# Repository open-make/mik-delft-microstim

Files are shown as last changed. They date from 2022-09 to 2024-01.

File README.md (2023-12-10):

# Hardware setup for the "Microstimulation" experiment 
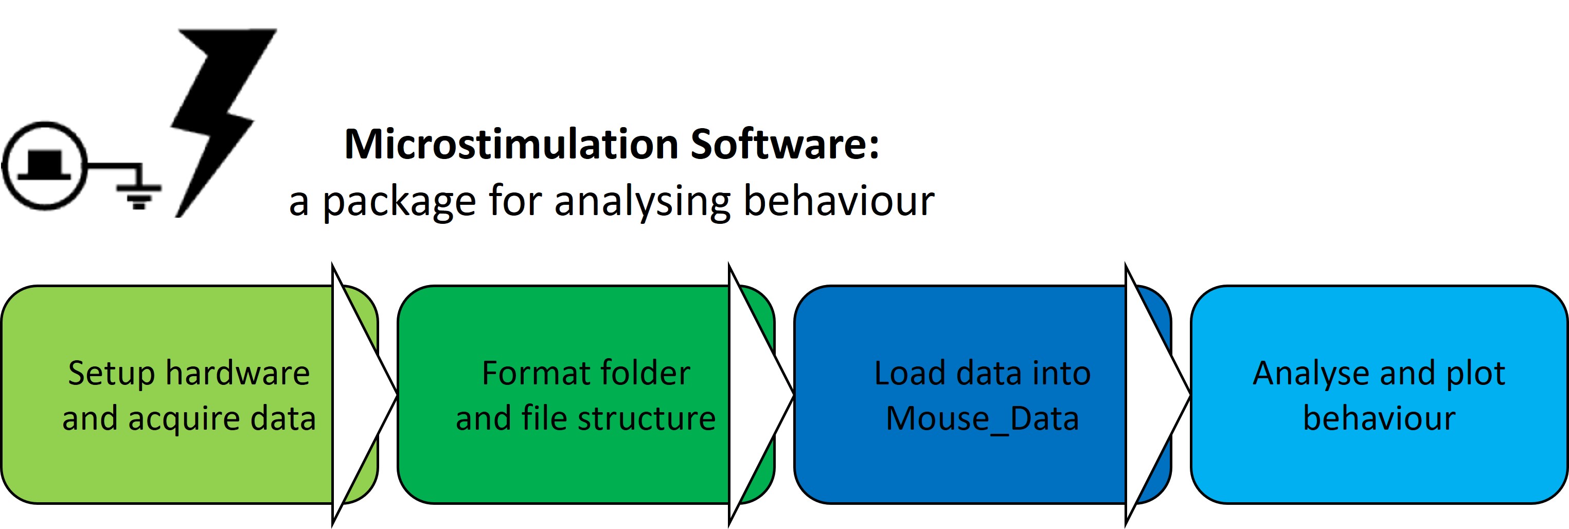
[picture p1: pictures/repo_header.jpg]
header


This repository provides information to set up the "Microstimulation" experiment used in Matthew Larkum's lab, including both *a documentation package of the hardware, the experimental protocol, and the software used for data acquisition* 
We will present here the most recent version which was reworked to use BPOD (Schutte et al. in preparation), we will also refer to the original setup described in (Doron et al., 2020).

In the microstimulation experiment, a *rodent* (usually a mouse) is head fixed. It receives *Intracranial Direct Current stimulation (IDCS)* or  *microstimulation* in the primary somatosensory barrel cortex (S1-BF). The goal of the task is to teach the animal to report the stimulus by licking a water spout during the response window. The animal usually learns to associate a 40 $\mu A$  stimulation with a sugar water (4% sucrose) reward and will lick the water tube upon stimulation. Both a BPOD and a SPIKE2 version of the setup and the protocol exist. 

## Current state of the project

The hardware can be defined as a prototype, as most self-assembled setups in neurobiology labs. Most components are not open source, and expensive. Note that things like the camera holder, rod-connector or head-bar holder can be found as 3D printable files from the [SimpleScienceSetup](https://github.com/mik-schutte/SimpleScienceSetup) project.

The current version uses [BPOD](https://sanworks.io/shop/products.php?productFamily=bpod) technology and [MATLAB](mathworks.com/campaigns/products/trials.html?gclid=CjwKCAiAmsurBhBvEiwA6e-WPC8ymdKjoKsw-h0QvnPUYUxUiHMEaFBh7Eg0xaEl5rYMuemgdsWKdBoC2_kQAvD_BwE&ef_id=CjwKCAiAmsurBhBvEiwA6e-WPC8ymdKjoKsw-h0QvnPUYUxUiHMEaFBh7Eg0xaEl5rYMuemgdsWKdBoC2_kQAvD_BwE:G:s&s_kwcid=AL!8664!3!462958882966!e!!g!!matlab%20download&s_eid=ppc_10961695282&q=matlab+download&gad_source=1) scripts, while the original setup used [CED 1401 and SPIKE2](https://ced.co.uk/products/spkovin). 

The goal of this repository is to provide a step-by-step guide for a non-engineer (neuroscientist) to create, build, implement and do experiments on the setup. The **future** of the project holds implementations for probe recordings, 2P-imaging and widefield imaging.

## Overview of the microstimulation setup

The microstimulation setup can be subdivided into several compartments:

* The [base setup](10_basesetup/base_readme.md): Components need to be brought together, everything needs to be grounded and vibration resistant. The elements should be hooked to the computer with possibly a good time synchronisation and cable management. Finally, micromanipulators should be positioned to maximize safe movement in the setup.

* The [animal restrains](11_animalrestrains/AR_readme.md): Headfixation and animal restrainment to allow for electrode insertion with limited discomfort. Positioning of the mouse holder should allow for flexibility for between-animal differences.

* The [water reward system](12_water-reward/WR_readme.md): The lick detector, the multitool, the solenoid, the tubing and the water container. Allowing for a quantified, timed and reliable distribution of the water reward.

* The [electrical compartment for stimulation and eventually recording](13_stimulation-recoding/stim_rec_readme.md): Comprised of the arduino pulse configurator, the stimulus isolator, the electrode, and the electrode holder. Together, they are used to generate an electrical stimulation that's emitted through the electrode.

* The [camera compartment](14_videorecording/vid_r_readme.md): Contains the cameras, the camera holders, the lenses, the infra-red and the UV-light. Collectively they allow for the recording of animal behaviour such as pupil dilation and whisker movement.

All compartments put together create a setup that should roughly look like this. 

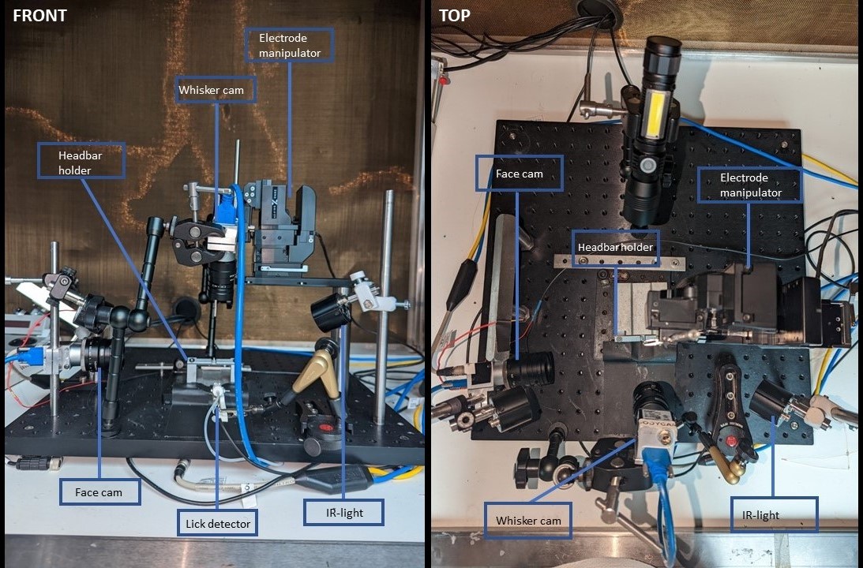
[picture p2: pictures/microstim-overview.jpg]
Overview of the setup from the side and from above


## Description of repository content

This repository largely follows a similar structure as the setup. Each hardware compartment (see above) has their own folder with a README, a bill of materials, build instructions and a wiring diagram. This allows for a modular and more flexible setup that is necessary for easy adoption. 

You'll notice that sometimes a difference is made between version 0 and version 1. This means that there is a difference in this compartments laboratory interface. The laboratory interface is used to coordinate the experiments here it determines what to do with licking input, when to give a microstimulation and when to start saving frames. Version 0 corresponds to the SPIKE2 implementation and version 1 to the BPOD implementation.

## The Software

On top of the hardware documentation we also provide a software package for analysing behavioural and video data. All can be found on the GitHub page for [Microstimulation analysis](https://github.com/mik-schutte/Microstimulation). We have already created a notebook on how to perform analysis. We highly-reccomend checking it out for those with similar data.

## How to contribute 

If you have been reading until here, you can probably help us make this documentation better. Please contact us per email or via an issue in this repository, especially if you are using this documentation, if you have some comments or ideas for improvement, if you want to reuse this hardware for similar or dissimilar experiments or if you just want to say hello. 

## Acknowledgements

The core team members are Mik Schutte and Jelte de Vries. Both of us are employed by the Humboldt University and PhD-students in the Larkum lab and are being supervised by Dr. Robert Sachdev. Primary development was performed by Dr. Guy Doron and transferred by Moritz Druke. Data-management and the supervision concerning open source is done by Dr. Julien Colomb. Lastly, we thank the Delft Open Hardware Academy for its many valuable lessons in designing, project management and hardware documentation.

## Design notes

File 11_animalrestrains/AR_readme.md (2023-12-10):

# Animal Restraint Compartment

The animal restraints section focuses on head fixation and animal restraint to facilitate electrode insertion while ensuring minimal discomfort for the subject. Considerations are made to provide a comfortable experience during experiments.

## Purpose
Prioritizing minimal discomfort and adapting to biological and surgical deviations is pivotal. This approach ensures the animal's comfort throughout the experiments, contributing to standardized and reliable video data acquisition. By minimizing stress or discomfort, the animal is better poised to participate comfortably in experimental tasks while supporting consistent data collection.

The design and setup of the animal restraint compartment considers the well-being of the subject, aligning with ethical considerations and the need for standardized data acquisition protocols. Two main points are to be optimized:

1. **Headfixation:** Enabling stable head positioning for precise electrode insertion and minimizing movement during experiments.
   
2. **Comfort and Flexibility:** Positioning of the mouse holder is designed to accommodate variations between animals, ensuring adaptability for different biological and surgical conditions. This flexibility is crucial for maintaining the animal's comfort and enabling consistent experimental procedures.

### Testing 
Anna Nasr, is working on a deep-learning based system for analyzind animal discomfort using the grimace scale (to be published).

## Necessary Tools

To build the animal restraint, You will need to have build the [base setup](10_basesetup\base_readme.md). Other than that, you will need the following tools:

- Plastic tube
- Headbar holder
- Rod connector
- 5cm rod
- 6mm hex screw (x4)
- 3mm nut

Some components such as the rod connector and a headbar holder are available as 3D printable files in the [SimpleScienceSetup]((https://github.com/mik-schutte/SimpleScienceSetup). Additionally, the exact tools used here, as well as, alternatives can be found in this folder's [bill of materials]().

## Build instructions

Animal Restraint Build

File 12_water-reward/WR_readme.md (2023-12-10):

# Water Reward Compartment

The water reward compartment within the microstimulation setup comprises distinct components crucial for precise and controlled delivery of rewards to the subject, usually a rodent, during experimental tasks. Each component serves a specific function in managing and administering the water reward.

## Components and Functionality

1. **Piezo Sensor Lick Detector:** This sensor is utilized to detect and register the subject's licking response. Piezo sensors convert mechanical pressure (in this case, the licking action) into electrical signals, triggering the delivery of the water reward upon the desired behavior completion.

2. **Multitool:** A workshop-provided tool utilized for managing the release of the water reward. It operates in conjunction with other components, facilitating controlled and timed delivery.

3. **Solenoid:** A separate component responsible for controlling the water flow. The solenoid regulates the water release triggered by the multitool's mechanism.

4. **Tubing:** The conduit through which the water reward is delivered from the source (water container) to the subject's access point.

## Special Considerations for Components

- **Lick Detector Holder:** Essential for the piezo sensor's placement, ensuring flexibility to accommodate variations among subjects. This holder's adaptability is crucial for positioning the sensor accurately for consistent detection.

### Working with Water: Safety Warning

Working with water in the experimental setup requires careful attention and adherence to safety protocols:

- **Electrical Safety:** Ensure all electrical components involved in water management are properly insulated and protected to prevent electrical hazards.
  
- **Hygiene and Contamination:** Regularly maintain and sterilize components that come into contact with water to prevent contamination and ensure the subject's health and safety.
  
- **Waste Disposal:** Dispose of used water responsibly to avoid environmental impact and maintain laboratory cleanliness.

Maintaining a safe working environment when handling water in the experimental setup is essential to safeguard both experimental integrity and the well-being of the subjects involved.

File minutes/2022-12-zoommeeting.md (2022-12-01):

# Present people
Mik, julien, mostafa

# discussion
- scientific question: behavior -  noisy system - 

# mik contract

- still no master thesis
- contract start 01.03 at the earliest
- arrive in Berlin mid January

# mostafa

- start moving to doing microstim
- want to do wide field/2P
- 

# Setup
- Jelte built one

- calcium imaging + electrostim: should not be too difficul if we have a chronic implant, with a special electrode just surfaceing the brain.

## Bpod
- seems to work actually !
- stimulator: Pulse Pal v2 
- https://www.wpiinc.com/var-2273-constant-current-stimulus-isolator
- 

MIK: work with GAlad lab
Implant: easy? who has experience. may need to change the protocol (current intensity)

TO do:
- finding someone to make implants / papers with description
- lageso issues about implants ?
- lageso permit for sfb projects.

- make it cheaper: Daniel from workshop could help?
- validation of stimulus: oscilloscope

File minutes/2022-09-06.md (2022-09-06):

Meeting on zoom

- julien 
- mik

## assurance and co

- assurance
- know about taxes
- accomodation
- delivery in Delft ?
- accessories: is there stuff to borrow, should we buy things. can things be printed.

## goals

- microstim setup dvt 
  - Bpod
  - implemented microelectrode
  - injector set
- microstim setup documentation
  - https://gin.g-node.org/larkumlab/Mik_microstimulation_hardwaresetup/src/master/data_acquisition.md
- Delft open science activities

### linked software

- data analysis - in python : see https://gin.g-node.org/larkumlab/juliencolomb_waterrewardexp_RDM/issues/4 for info about poulet lab data structure
- collecting data - from spike2 to python
- collecting data - gui (does Bpod comes with a gui ?)

## in Berlin

- best if done right after, so we know on the spot if the documentation works.
- see Poulet setup

##  whishes

- work after the 3 months as affiliated
- regular meeting, set deadlines/milestones

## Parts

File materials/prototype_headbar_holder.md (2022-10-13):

# Headpost holder prototyping
## Initial version

Step 1: Hypothesis
- Currently, the headbar holder is a solid piece of metal that doesn't counter any misplacements of the headposts, nor measure the amount of strain on it. However, I think it is possible to implement an adjustable angle of the headpost and a headstrain gage.
- This would enable a measure for animal discomfort during experimentations, as well as, reduce the effect of human mistakes.

Step 2: Test
- To verify that, we will first replicate the metal headbarholder holder in 3D printed form. 

- €
- Current version is reliable to work, but doesn't implement the above mentioned improvements.

Step 3: Metric
- Similarity to the original.

Step 4: Criteria
- We are right if the intial version can safely hold a mouse with headpost.

Learning documentation

Step 5: Observation
- We observed that ..... 

Step 6: Learning and insights
- From what we learned that ....

Step 7:
- Therefore, we will ... <what you will do after capturing this insight, perhaps new prototypes or different types of tests>

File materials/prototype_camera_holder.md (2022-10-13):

# Camera holder prototyping
## Initial version

Step 1: Hypothesis
- Currently, the holder for the cameras is in the form of a metal plate that can be attached to the bottom. However, I beleive that it is possible to replace this by a 3D printed attachement. 
- This would reduce the costs and the time spend waiting for it to arrive. Additionally, multiple versions can be created to allow for a flexible implementation.

Step 2: Test
- To verify that, we will replicate the metal camera holder in 3D printed form. 
- €
- Current version is not reliable at all as it doesn't take camera dimensions into account.

Step3: Metric
- And measure how tightly the holder can be attached to the camera

Step 4: Criteria
We are right if the camera holder can securely be connected to the camera and can be tightened to a rod.

Learning documentation

Step 5: Observation
- We observed that ..... 

Step 6: Learning and insights
- From what we learned that ....

Step 7:
- Therefore, we will ... <what you will do after capturing this insight, perhaps new prototypes or different types of tests>

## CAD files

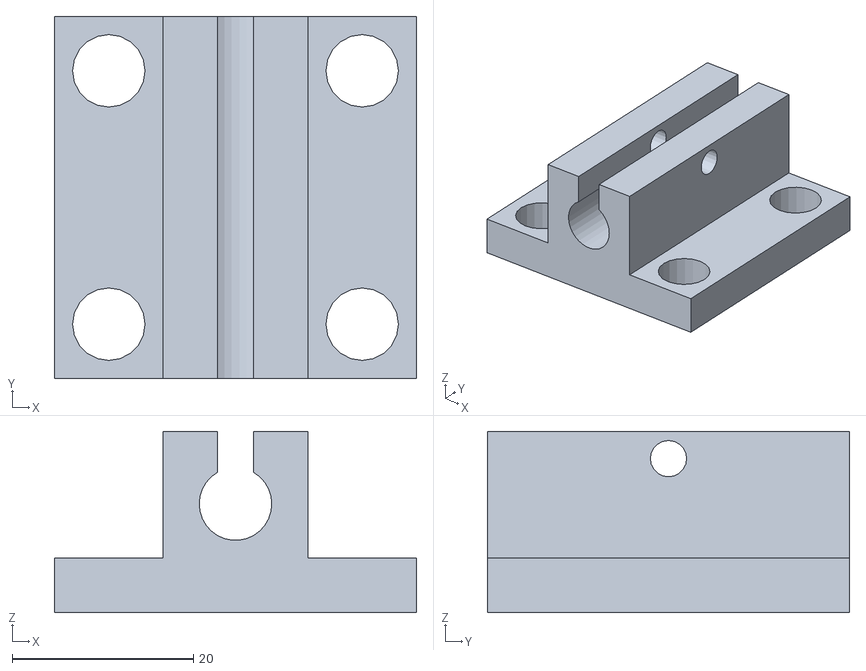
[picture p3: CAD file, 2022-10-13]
materials/baslercamera_holder.stl
40.0 x 40.0 x 20.0

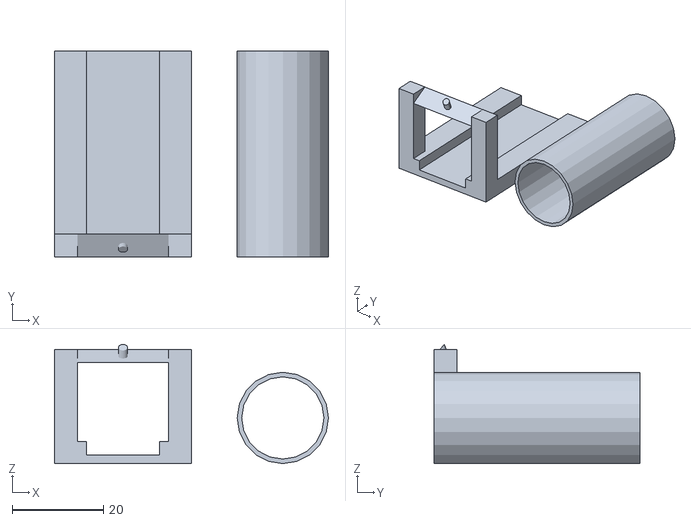
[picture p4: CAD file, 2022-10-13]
materials/headbar_holder.stl
60.0 x 45.0 x 26.1

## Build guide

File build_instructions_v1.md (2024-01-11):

# Build instructions

## Before you begin

Please note the current state of the project.
Currently, we are hard at work to make new developments for the microstimulation setup. This creates makes it difficult to keep all the documentation up-to-date. The first improvement is the conversion from CED to BPOD. With this transition the component that drives the setup will be adjusted. However, the instructions below work with the CED and Multitool as noted in the Bill of Materials.

## Tools required 

In order to replicate the microstimulation setup you need the following tools:
- Flat head screwdriver
- Hex key
- ???

## Wiring diagram
Julien's wiring diagram here

## Material required

|Base|Animal Restraint|Water Reward|Stimulation|Video|
|----|---|---|---|-----|
|Vibration table|
|6mm breadboard| 
|Hex screw (xmm?)|
|

## Animal component and reward system

Attache the headbar holder to the breadboard and connecting the lick detector to the multitool.

1. Place the headbar holder on the breadboard.
2. Screw in the 6mm hex screws to fasten the headbar holder.
3. Place the lick detector in front of the headbar holder.

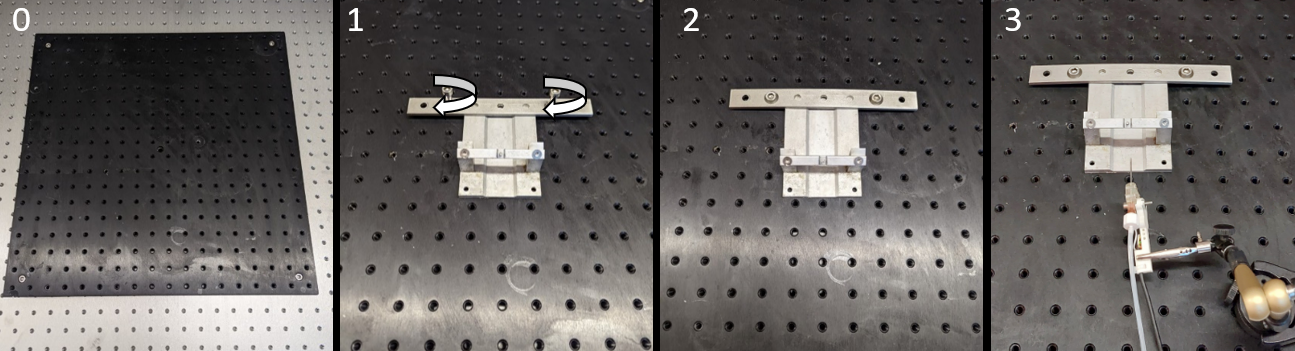
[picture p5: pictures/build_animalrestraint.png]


5. Connect the lick detector with the multitool at PIEZO IN.
6. Connect Multitool TRIGGER OUT with the CED EVENT IN 0, using a BNC connector.
7. Connect Multitool SOLENOID IN with the CED DIGITAL OUT 0, using a BNC connector.
8. Connect Multitool SOLENOID OUT with the solenoid.
9. Connect the tubing from the water container to the spout of the lick detector.

![](pictures/build_ced_multi.png

If correctly configured you can now turn on the Multitool and gently tap the lick detector. There should be a light coming from TRIGGER OUT. If it doesn't try increasing the GAIN of the signal by turning the knob on the Multitool. 

Additionally, test if the solenoid is working by pressing the SOLENOID SETUP know. You should hear the solenoid opening with a click. If you have also filled your water container water should now be despensed from the licking spout.

## Electrical component

Set up the micromanipulator, attach electrode holder to the manipulator, connect the stimulus isolator to the CED and optionally clamp the electrode with the electrode holder and connect to the stimulus isolator.

1. Place your micromanipulator to the side of the headbar holder. Make sure that the holder can be reached by the manipulator. Note that an electrode will be attached and should safely hover over the headbar holder.
2. Connect CED EVENT IN 1 to CED DIGITAL OUT 1 using a BNC connector.
3. Connect CED DIGITAL OUT 1 to the stimulus isolator INPUT using a BNC connector.
4. Attach the electrode holder to the micromanipulator.
5. Clamp the electrode using the electrode holder. Be very carful during this step as the electrode is very delicate.
6. Connect the electrode to the stimulus isolator OUTPUT.



If correctly connected you can try testing the electrical compartment. Turn on the stimulus isolator and switch AUDIO to and OUTPUT to on. Turn on the CED and open the SPIKE2 script. Place the electrode in saline together with the grounding (red) wire. The SPIKE2 script should allow you to give a stimulus. You should see a light at CED EVENT IN 1 as well as hear a beep from the stimulus isolator.

## Camera component

Place the camera holders on the breadboard, mount the cameras to their holders and connect the cameras to the computer and the CED.

1. Position the camera holders at the angle of interest. The distance from the headbar holder depends on your camera and it's lense. You can use this STL file for determining the best position.
2. Mount the cameras to their holder.
3. Connect the cameras to your computer using the USB 3.0, Micro B sl/A cable.
4. Connect the cameras to the CED DAC OUT 0 using the Opto-GP-I/O Y cable. If you are using the supplied camera configuration GPIO 3 should be connecting the camera and the CED.
5. Connect CED DAC OUT 0 to CED ADC IN 3.



If succesful you can try out the cameras by opening up the Pylon recording software and selecting the supplied configuration file. Try giving a stimulus, if everything is connected properly frame aquisition should start.

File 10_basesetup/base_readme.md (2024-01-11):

# Building the Microstimulation Setup

## Preliminary Notes
Please take into account the current status of the project. We're actively working on advancements for the microstimulation setup, which may affect the documentation's completeness. The change from version0 to version1 has transfered the laboratory interface from CED to BPOD. However, the instructions provided below are compatible with both versions. You can find the specific components in the [bill_of_materials](base_setup/base_BoM.csv) 

## Purpose
The base setup serves as the foundation for the entire microstimulation experiment. Its primary functions to minimize vibrations, ensuring a stable platform for the experiment. This stability is crucial for accurate data collection and the functionality of delicate equipment.

For stability, we employ a vibration isolation workstation with an accompanying optical breadboard. For prototyping your setup you can use tools from the [SimpleScienceSetup](https://github.com/mik-schutte/SimpleScienceSetup) as an alternative. We ground all components of the setup by connecting them to the building ground with low resistance braided copper wires. 

The base setup acts as a platform for integrating and arranging the various compartments necessary for the experiment:

1. **Animal Restraints:** This section includes components for head fixation and animal restraint to facilitate electrode insertion while minimizing discomfort for the subject.

2. **Water Reward System:** Components such as the lick detector, multitool, solenoid, tubing, and water container are situated within this section to ensure precise and reliable delivery of the water reward.

3. **Electrical Compartment:** Components like the arduino pulse configurator, stimulus isolator, electrode, and electrode holder are placed here to generate and emit electrical stimulation through the electrode.

4. **Camera Compartment:** This section houses cameras, camera holders, lenses, infra-red, and UV-light setups, enabling the recording of various behavioral aspects such as pupil dilation and whisker movement.

The base setup's strategic design and placement of these compartments ensure a cohesive and functional microstimulation setup.

## Necessary Tools

To replicate the base microstimulation setup, you will need the following:

- Vibration isolation workstation [Vision Isostation](https://www.newport.com/c/vision-isostations)
- Optical breadboard (M6)
- Thorlab rod (x2)
- Micromanipulator(s)
- Grounding box and wires
- M6 hex key
- 6mm hex screw (x2)

## Build instructions
Animal Restraint Build
image: table, table+breadboard,

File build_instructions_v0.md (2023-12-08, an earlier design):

# Build instructions

## Before you begin

Please note the current state of the project.
Currently, we are hard at work to make new developments for the microstimulation setup. This creates makes it difficult to keep all the documentation up-to-date. The first improvement is the conversion from CED to BPOD. With this transition the component that drives the setup will be adjusted. However, the instructions below work with the CED and Multitool as noted in the Bill of Materials.

## Tools required 

In order to replicate the microstimulation setup you need the following tools:
- Flat head screwdriver
- Hex key
- ???

## Wiring diagram

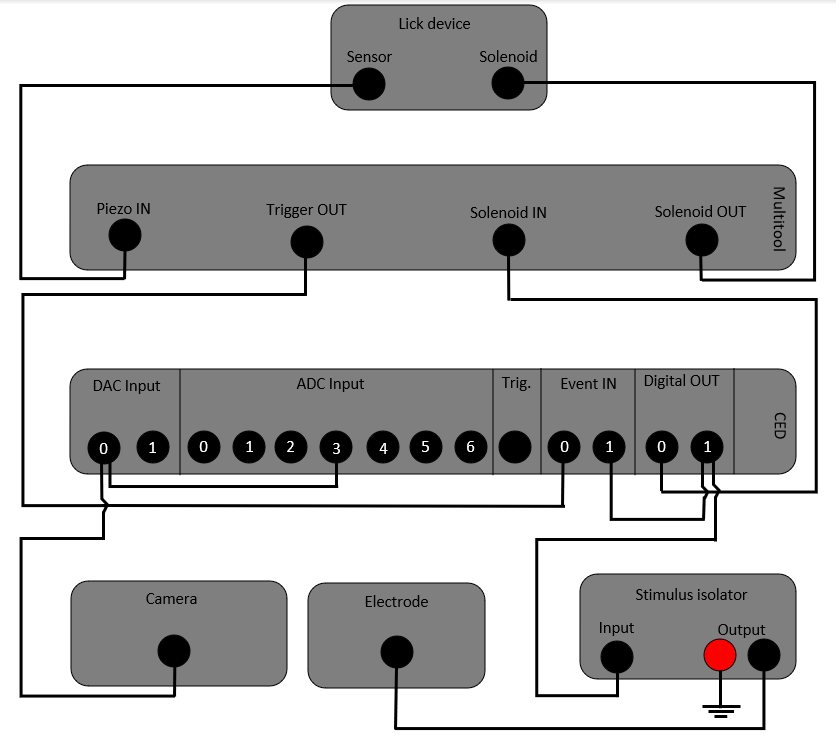
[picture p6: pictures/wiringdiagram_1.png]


## Material required

|Animal component|Electrical component|Behavioural component|
|---|---|---|
|6mm Breadboard| Stimulus isolator| Camera|
| Headbar holder| Micromanipulator| Camera holder|
| 6mm hex screw (x2)| Electrode holder| IR-light (x2)|
| Lick detector| Tungsten electrode| UV-light|
| Multitool| BNC connector (x2)| USB 3.0, Micro B sl/A
| Solenoid| | Opto-GP-I/O Y Cable|
| Tubing|
| Water container/syringe|
| BNC connector (x2)|

## Animal component and reward system

Attache the headbar holder to the breadboard and connecting the lick detector to the multitool.

1. Place the headbar holder on the breadboard.
2. Screw in the 6mm hex screws to fasten the headbar holder.
3. Place the lick detector in front of the headbar holder.



5. Connect the lick detector with the multitool at PIEZO IN.
6. Connect Multitool TRIGGER OUT with the CED EVENT IN 0, using a BNC connector.
7. Connect Multitool SOLENOID IN with the CED DIGITAL OUT 0, using a BNC connector.
8. Connect Multitool SOLENOID OUT with the solenoid.
9. Connect the tubing from the water container to the spout of the lick detector.

![](pictures/build_ced_multi.png

If correctly configured you can now turn on the Multitool and gently tap the lick detector. There should be a light coming from TRIGGER OUT. If it doesn't try increasing the GAIN of the signal by turning the knob on the Multitool. 

Additionally, test if the solenoid is working by pressing the SOLENOID SETUP know. You should hear the solenoid opening with a click. If you have also filled your water container water should now be despensed from the licking spout.

## Electrical component

Set up the micromanipulator, attach electrode holder to the manipulator, connect the stimulus isolator to the CED and optionally clamp the electrode with the electrode holder and connect to the stimulus isolator.

1. Place your micromanipulator to the side of the headbar holder. Make sure that the holder can be reached by the manipulator. Note that an electrode will be attached and should safely hover over the headbar holder.
2. Connect CED EVENT IN 1 to CED DIGITAL OUT 1 using a BNC connector.
3. Connect CED DIGITAL OUT 1 to the stimulus isolator INPUT using a BNC connector.
4. Attach the electrode holder to the micromanipulator.
5. Clamp the electrode using the electrode holder. Be very carful during this step as the electrode is very delicate.
6. Connect the electrode to the stimulus isolator OUTPUT.



If correctly connected you can try testing the electrical compartment. Turn on the stimulus isolator and switch AUDIO to and OUTPUT to on. Turn on the CED and open the SPIKE2 script. Place the electrode in saline together with the grounding (red) wire. The SPIKE2 script should allow you to give a stimulus. You should see a light at CED EVENT IN 1 as well as hear a beep from the stimulus isolator.

## Camera component

Place the camera holders on the breadboard, mount the cameras to their holders and connect the cameras to the computer and the CED.

1. Position the camera holders at the angle of interest. The distance from the headbar holder depends on your camera and it's lense. You can use this STL file for determining the best position.
2. Mount the cameras to their holder.
3. Connect the cameras to your computer using the USB 3.0, Micro B sl/A cable.
4. Connect the cameras to the CED DAC OUT 0 using the Opto-GP-I/O Y cable. If you are using the supplied camera configuration GPIO 3 should be connecting the camera and the CED.
5. Connect CED DAC OUT 0 to CED ADC IN 3.



If succesful you can try out the cameras by opening up the Pylon recording software and selecting the supplied configuration file. Try giving a stimulus, if everything is connected properly frame aquisition should start.

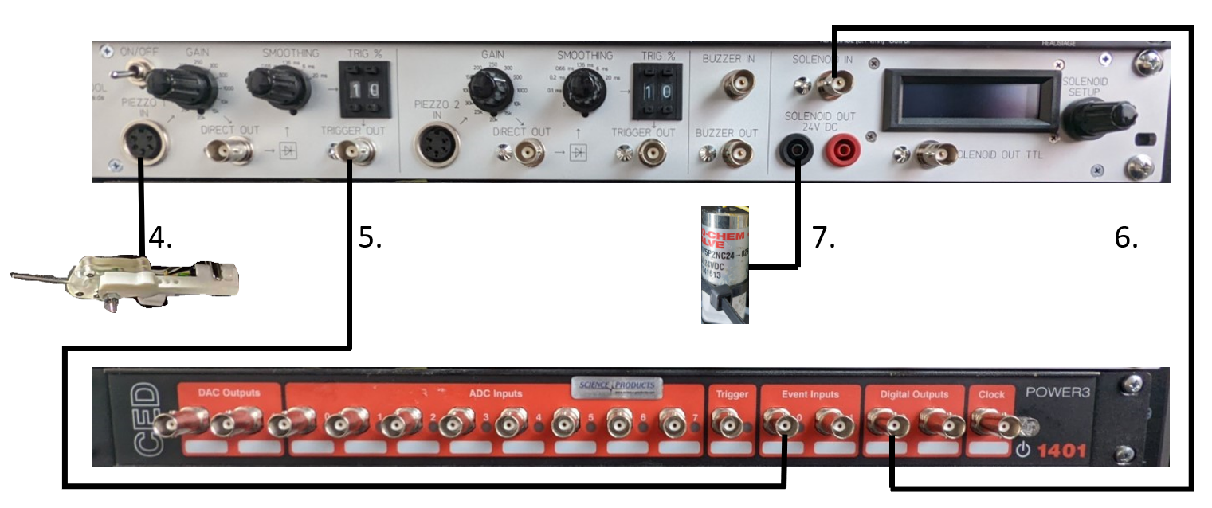
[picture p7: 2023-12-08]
pictures/build_ced_multi.png

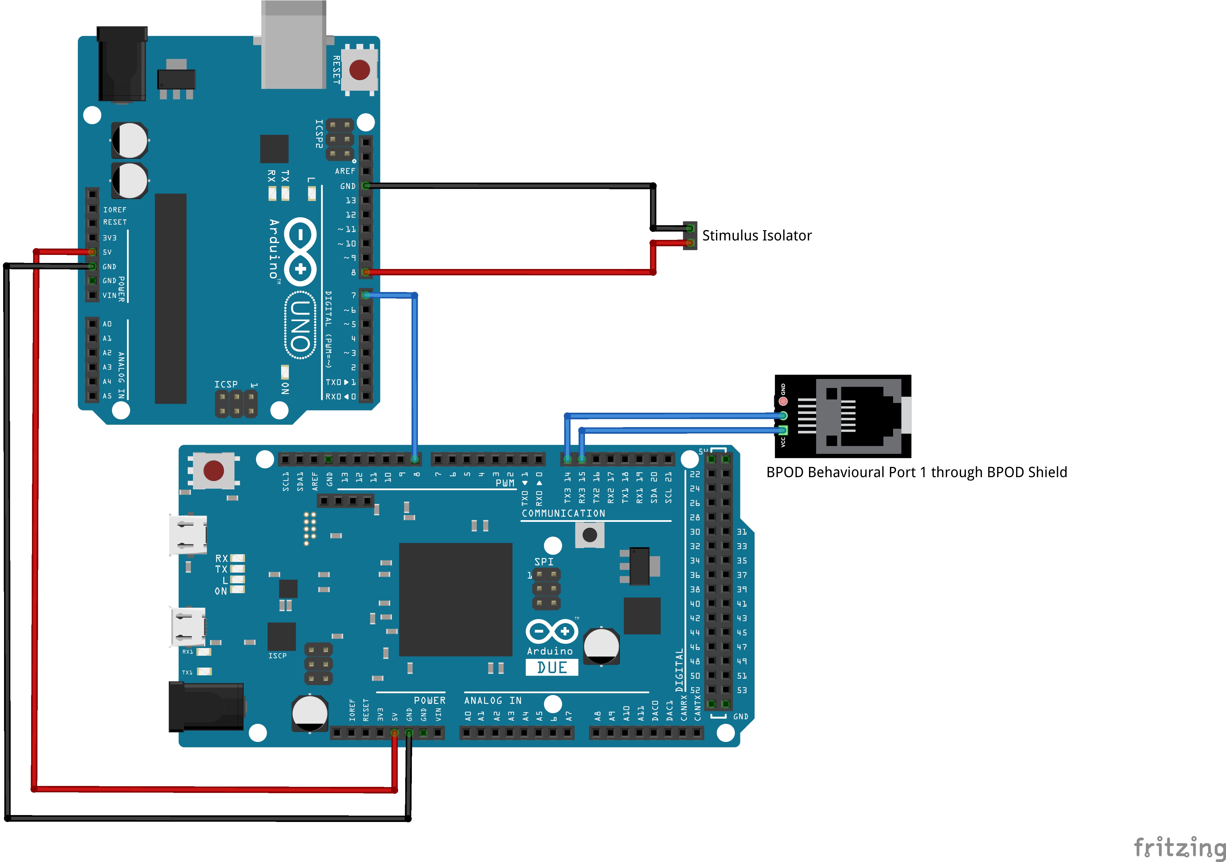
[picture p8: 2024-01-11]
pictures/Arduino_wiringDiagram.jpg

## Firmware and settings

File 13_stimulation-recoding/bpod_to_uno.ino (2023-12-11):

// The Arduino DUE is used to transfer the signal from the BPOD to the pulse-configuring Arduino UNO.
// We have to ues the DUE, because the BPOD only interfaces through a BPOD shield: https://sanworks.github.io/Bpod_Wiki/assembly/arduino-shield-gen2-assembly/. But the DUE only outputs 3.3V

int stimPin = 8; // Pin to send TTL signal from DUE to UNO

void setup() {
  Serial.begin(1312500); // Set serial communication rate to match the BPOD
  pinMode(stimPin, OUTPUT); // Set pin 8 as an output
}

void loop() {
  if (Serial.available() > 0) { // Check if there's incoming data
    char data_rcvd = Serial.read(); // Read the received data
    if (data_rcvd == '1') {
      digitalWrite(stimPin, HIGH); // Send HIGH signal to the UNO
    } else if (data_rcvd == '0') {
      digitalWrite(stimPin, LOW); // Send LOW signal to the UNO
    }
  }
}

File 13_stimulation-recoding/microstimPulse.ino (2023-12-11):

int stimPin = 8; //which pin to use to turn on the stimulus isolator
int inputPin = 7; //the pin that receives the input from the Arduino DUE with the BPOD shield
void setup() {
  Serial.begin(9600); 
  pinMode(stimPin, OUTPUT); //pin 8 is output
  pinMode(inputPin, INPUT); //pin 7 receives input
}

void loop() {
    if(digitalRead(inputPin, HIGH) { //this means that the UNO receives a ttl from the DUE
        for (int i = 0; i< 40; i++) { //loop that turns pin8 on or off with the delay as frequency 
        digitalWrite(stimPin,HIGH); 
        delay(0.3);
        digitalWrite(stimPin,LOW);
        delay(4.7);
      }
    }
    
    else  {
      digitalWrite(stimPin,LOW); 
    }
  }
}

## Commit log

2022-10-05 initial commit
    Description and current state of the project.
2022-10-12 Created bill of materials
    description, costs and where to find
2022-10-13 created materials folder
    and added camera_holder prototyping markdown
2022-10-13 initial commit headbar_holder prototype
    only markdown
2022-10-13 added prototype STL-files
    for headbar and camera holder
    [baslercamera_holder.stl, headbar_holder.stl]
2022-11-09 updated build_instructions
    added full wiring diargam
2023-01-24 Update README.md
    new current state
2023-12-01 review part 1, set up for more modularity, spreadsheet for BOM, add figures (not 100%)
